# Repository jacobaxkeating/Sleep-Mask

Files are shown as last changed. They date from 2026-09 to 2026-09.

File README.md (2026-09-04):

# Circadian Sleep Mask

## Overview
A battery powered sleep mask that gradually illuminates the inside of the mask as the user's alarm approaches. The user sets their sleep duration by pressing a button on the housing, and the device begins lighting up that many hours later. Waking this way is closer to how the body wakes naturally, easing the user out of sleep rather than jolting them awake. It reduces sleep inertia, the grogginess and disorientation that follows an abrupt alarm

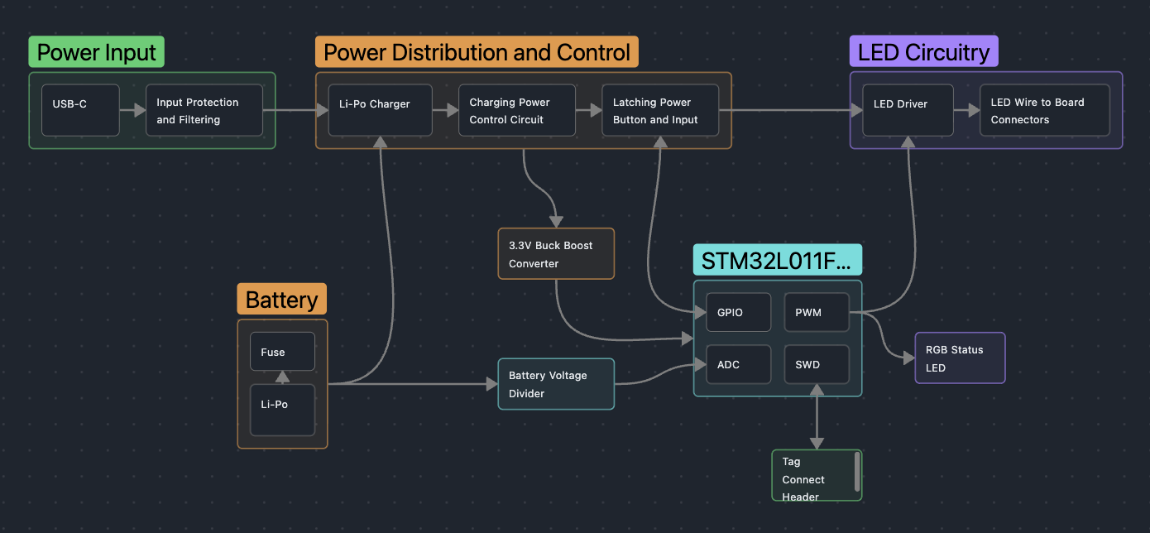
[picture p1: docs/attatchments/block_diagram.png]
Block Diagram


[Schematic (PDF)](outputs/schematic/sleep_mask.pdf)

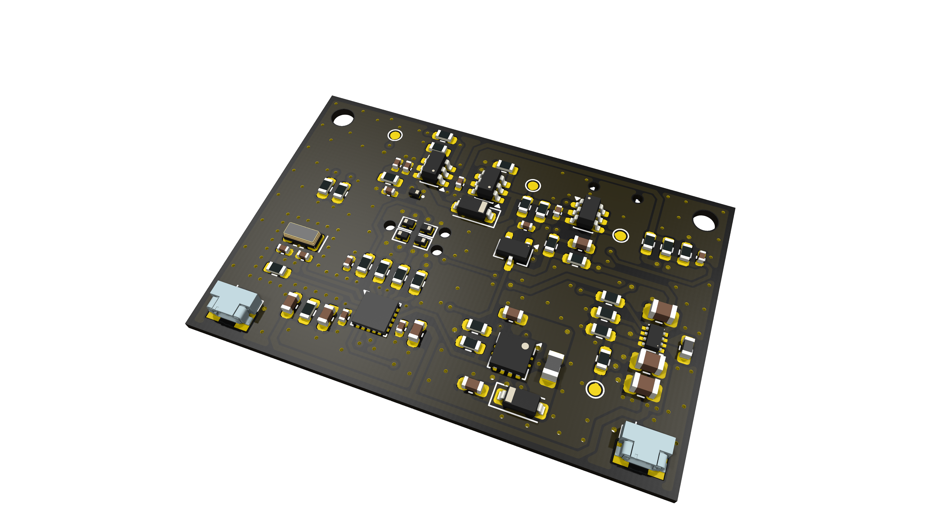
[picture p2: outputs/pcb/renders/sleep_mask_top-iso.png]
Sleep mask Front PCB

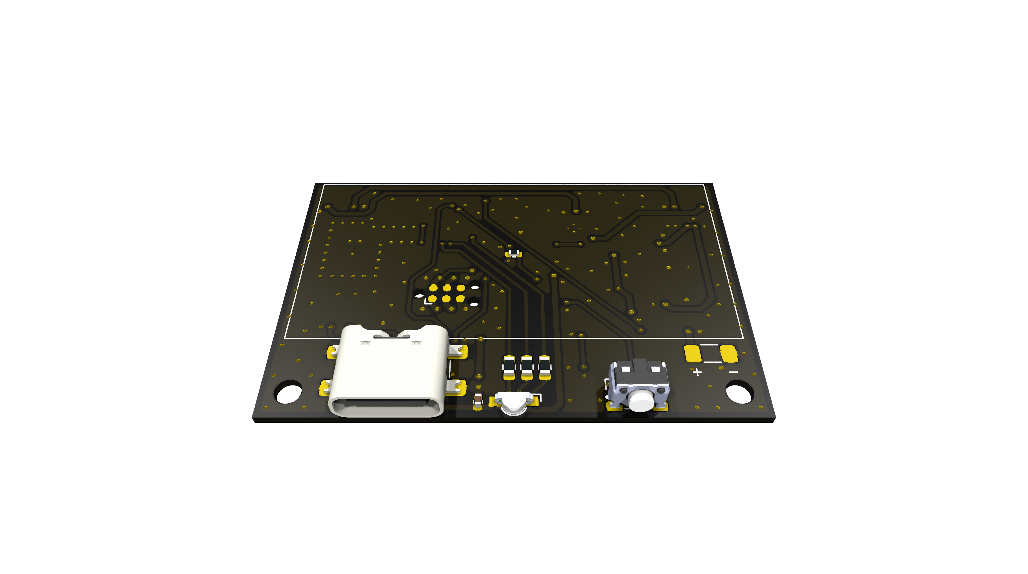
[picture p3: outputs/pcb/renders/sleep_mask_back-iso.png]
Sleep mask Back PCB


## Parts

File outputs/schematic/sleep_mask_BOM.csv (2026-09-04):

Reference | Value | Qty | MPN1 | Manufacturer1 | Footprint | Datasheet | COO | DNP | Description | MPN2 | Manufacturer2
BT1 | LP802036JU | 1 |  |  | Resistor_SMD:R_1206_3216Metric_Pad1.30x1.75mm_HandSolder | https://www.jauch.com/downloadfile/5ef1edcfd8b3ac6cf0afebf9dd427a79b/matd_248862_20220510_480mah_-_lp802036ju_1s1p_2_wire_50mm.pdf |  |  | BATTERY 3.7V 500MAH
C1,C2,C3,C4,C11,L2 | 1u | 6 |  |  | Capacitor_SMD:C_0402_1005Metric,Inductor_SMD:L_0603_1608Metric | https://mm.digikey.com/Volume0/opasdata/d220001/medias/docus/609/CL05A105KO5NNNC_Spec_5-2-19.pdf,https://search.murata.co.jp/Ceramy/image/img/P02/JETE243A-003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 |  |  | CAP CER 1UF 16V X5R 0402,FIXED IND 1UH 1.7A 128 MOHM SMD
C5,C7,C14,C15,C17,C18 | 100n | 6 |  |  | Capacitor_SMD:C_0402_1005Metric | https://mm.digikey.com/Volume0/opasdata/d220001/medias/docus/609/CL05B104KO5NNNC.pdf |  |  | CAP CER 0.1UF 16V X7R 0402
C6,C16,C19,C20 | 10u | 4 |  |  | Capacitor_SMD:C_0603_1608Metric | https://mm.digikey.com/Volume0/opasdata/d220001/medias/docus/43/CL10X106MO8NRNC_Spec.pdf |  |  | CAP CER 10UF 16V X6S 0603
C8,C9,C10 | 22u | 3 |  |  | Capacitor_SMD:C_0805_2012Metric | https://mm.digikey.com/Volume0/opasdata/d220001/medias/docus/339/CL21A226MAYNNNE_Spec.pdf |  |  | CAP CER 22UF 25V X5R 0805
C12,C13,L3 | 4.7u | 3 |  |  | Capacitor_SMD:C_0603_1608Metric,Inductor_SMD:L_0805_2012Metric | https://product.tdk.com/en/system/files |  |  | CAP CER 4.7UF 35V X5R 0603,FIXED IND 4.7UH 600MA 180 MOHM
C21,C22 | 8p | 2 |  |  | Capacitor_SMD:C_0402_1005Metric | https://mm.digikey.com/Volume0/opasdata/d220001/medias/docus/7513/DataSheet_CL05C080DB51PN_20251013.pdf |  |  | CAP CER 8PF 50V C0G/NP0 0402
D1,D5 | MBR0520LT1G | 2 |  |  | Diode_SMD:D_SOD-123 | https://www.onsemi.com/pdf/datasheet/mbr0520lt1-d.pdf |  |  | DIODE SCHOTTKY 20V 500MA SOD123
D2,D3 | TPD1E10B06DPYR | 2 |  |  | Package_SON:Texas_DPY0002A_0.6x1mm_P0.65mm | https://www.ti.com/general/docs/suppproductinfo.tsp?distId=10 |  |  | TVS DIODE 5.5VWM 14VC 2X1SON
D4 | BAV99,215 | 1 |  |  | Package_TO_SOT_SMD:TSOT-23 | https://assets.nexperia.com/documents/data-sheet/BAV99.pdf |  |  | DIODE ARR GP 100V 215MA TO-236AB
D6,D7,D8,D9 | DF2B5M4CT,L3F | 4 |  |  | Diode_SMD:D_SOD-882 | https://toshiba.semicon-storage.com/info/docget.jsp?did=55770&prodName=DF2B5M4CT |  |  | TVS DIODE 3.6VWM 15VC CST2
D10 | APFA3010 | 1 |  |  | LED_SMD:LED_Kingbright_APFA3010_3x1.5mm_Horizontal | https://www.KingbrightUSA.com/images/catalog/SPEC/APFA3010LSEEZGKQBKC.pdf |  |  | LED RGB CLEAR 4SMD R/A
F1 | FUSE | 1 |  |  | Resistor_SMD:R_0603_1608Metric | https://www.vishay.com/docs/28747/mfuserie.pdf |  |  | FUSE BOARD MOUNT 1A 32VDC 0603
H3 | 2147192020 | 1 |  |  |  | https://www.molex.com/en-us/products/part-detail/2147192020?display=pdf |  |  | CONN HDR HSG 2POS 0.80MM
H4 | 2147205001 | 1 |  |  |  | https://www.molex.com/pdm_docs/sd/2147205001_sd.pdf |  |  | ZERO-HACHI 0.8 CRIMP TERM #30-32
J1 | USB4135-GF-A | 1 |  |  | Connector_USB:USB_C_Receptacle_GCT_USB4135-GF-A_6P_TopMnt_Horizontal | https://gct.co/files/specs/usb4135-spec.pdf |  |  | USB C REC GF RA 6P SMT & SMT SHE
J2,J4 | 2147210021 | 2 |  |  | sleep_mask:2147210021 | https://www.molex.com/en-us/products/part-detail/2147210021?display=pdf |  |  | ZERO-HACHI 0.8 HDR SR RA ETP AU
L1 | 27n | 1 |  |  | Inductor_SMD:L_0603_1608Metric | https://search.murata.co.jp/Ceramy/image/img/P02/JELF243B-0002.pdf |  | DNP | FIXED IND 27NH 500MA 550 MOHM
Q1 | DMP2240UDM | 1 |  |  | Package_TO_SOT_SMD:SOT-23-6 | https://www.diodes.com/assets/Datasheets/ds31197.pdf |  |  | MOSFET 2P-CH 20V 2A SOT26
Q2 | DMC2700UDM-7 | 1 |  |  | Package_TO_SOT_SMD:SOT-23-6 | https://www.diodes.com/assets/Datasheets/DMC2700UDM.pdf |  |  | MOSFET N/P-CH 20V 1.34A SOT26
R1,R25,R27 | 0 | 3 |  |  | Resistor_SMD:R_0603_1608Metric | https://yageogroup.com/content/datasheet/asset/file/PYU-RC_GROUP_51_ROHS_L |  |  | RES 0 OHM JUMPER 1/10W 0603
R2,R6,R9,R13,R16,R20,R28 | 10k | 7 |  |  | Resistor_SMD:R_0603_1608Metric | https://www.koaspeer.com/pdfs/RK73H.pdf |  |  | RES 10K OHM 1% 1/10W 0603
R3,R4 | 5.1k | 2 |  |  | Resistor_SMD:R_0603_1608Metric | https://www.koaspeer.com/pdfs/RK73H.pdf |  |  | RES 5.1K OHM 1% 1/10W 0603
R5 | 5.6k | 1 |  |  | Resistor_SMD:R_0603_1608Metric | https://yageogroup.com/content/datasheet/asset/file/PYU-RC_GROUP_51_ROHS_L |  |  | RES 5.6K OHM 1% 1/10W 0603
R7,R8,R10 | 100k | 3 |  |  | Resistor_SMD:R_0603_1608Metric | https://www.koaspeer.com/pdfs/RK73H.pdf |  |  | RES 100K OHM 1% 1/10W 0603
R11,R14 | 300k | 2 |  |  | Resistor_SMD:R_0603_1608Metric | https://www.koaspeer.com/pdfs/RK73H.pdf |  |  | RES 300K OHM 1% 1/10W 0603
R12 | 511k | 1 |  |  | Resistor_SMD:R_0603_1608Metric | https://www.koaspeer.com/pdfs/RK73H.pdf |  |  | RES 511K OHM 1% 1/10W 0603
R15 | 91k | 1 |  |  | Resistor_SMD:R_0603_1608Metric | https://yageogroup.com/content/datasheet/asset/file/PYU-RC_GROUP_51_ROHS_L |  |  | RES 91K OHM 1% 1/10W 0603
R17,R18,R19 | 49R9 | 3 |  |  | Resistor_SMD:R_0603_1608Metric | https://yageogroup.com/content/datasheet/asset/file/PYU-RC_GROUP_51_ROHS_L |  |  | RES 49.9 OHM 1% 1/10W 0603
R21 | R | 1 |  |  | Resistor_SMD:R_0603_1608Metric |  |  |  | ~
R22,R23,R26 | 1k | 3 |  |  | Resistor_SMD:R_0603_1608Metric | https://www.koaspeer.com/pdfs/RK73H.pdf |  |  | RES 1K OHM 1% 1/8W 0603
R24 | 49R9 | 1 |  |  | Resistor_SMD:R_0603_1608Metric | https://yageogroup.com/content/datasheet/asset/file/PYU-RC_GROUP_51_ROHS_L |  | DNP | RES 49.9 OHM 1% 1/10W 0603
SW1 | PWR/IN | 1 |  |  | Button_Switch_SMD:SW_Push_1P1T-MP_NO_Horizontal_Alps_SKRTLAE010 | https://tech.alpsalpine.com/cms.media/product_spec_skrtlae010_en_1db35b7ed3.pdf |  |  | SWITCH TACTILE SPST-NO 0.05A 12V
TH1 | NTC | 1 |  |  | Resistor_SMD:R_0402_1005Metric | https://product.tdk.com/system/files/dam/doc/product/sensor/ntc/chip-ntc-thermistor/catalog/tpd_commercial_ntc-thermistor_ntcg_en.pdf |  |  | THERMISTOR NTC 10KOHM 3380K 0402
TP1 | VBUS | 1 |  |  | TestPoint:TestPoint_Pad_D1.0mm |  |  |  | ~
TP2 | BATT_VBUS | 1 |  |  | TestPoint:TestPoint_Pad_D1.0mm |  |  |  | ~
TP3 | VCC | 1 |  |  | TestPoint:TestPoint_Pad_D1.0mm |  |  |  | ~
TP4 | 3.3V | 1 |  |  | TestPoint:TestPoint_Pad_D1.0mm |  |  |  | ~
U1 | BQ21040DBV | 1 |  |  | Package_TO_SOT_SMD:SOT-23-6 | https://www.ti.com/general/docs/suppproductinfo.tsp?distId=10 |  |  | IC BATT CHG LI-ION 1CELL SOT23-6
U2 | TPS631000 | 1 |  |  | Package_TO_SOT_SMD:SOT-583-8 | https://www.ti.com/lit/ds/symlink/tps631000.pdf |  |  | IC REG BUCK BOOST ADJ 2A SOT-583
U3 | TPS61043 | 1 |  |  | Package_DFN_QFN:Texas_DRB0008A | https://www.ti.com/lit/ds/slvs465c/slvs465c.pdf |  |  | IC LED DRVR RGLTR PWM 60MA 8SON
U4 | STM32L011F3U6TR | 1 |  |  | Package_DFN_QFN:ST_UFQFPN-20_3x3mm_P0.5mm | https://www.st.com/resource/en/datasheet/stm32l011f3.pdf |  |  | IC MCU 32BIT 8KB FLASH 20UFQFPN
Y1 | 830009706 | 1 |  |  | Crystal:Crystal_SMD_G8-2Pin_3.2x1.5mm | https://www.we-online.com/components/products/datasheet/830009706.pdf |  |  | CRYSTAL 32.7680KHZ 9PF SMD

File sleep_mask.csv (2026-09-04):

Reference | Qty | Value | Description | Manufacturer_Part_Number | DNP | Exclude from BOM | Exclude from Board | MPN | Manufacturer
BT1 | 1 | LP802036JU | BATTERY 3.7V 500MAH | LP802036JU +PCM+2IC+2 WIRES 50MM |  |  |  |  | Jauch Quartz
C1,C2,C3,C4,C11 | 5 | 1u | CAP CER 1UF 16V X5R 0402 | CL05A105KO5NNNC |  |  |  |  | Samsung Electro-Mechanics
C5,C7,C14,C15,C17,C18 | 6 | 100n | CAP CER 0.1UF 16V X7R 0402 | CL05B104KO5NNNC |  |  |  |  | Samsung Electro-Mechanics
C6,C16,C19,C20 | 4 | 10u | CAP CER 10UF 16V X6S 0603 | CL10X106MO8NRNC |  |  |  |  | Samsung Electro-Mechanics
C8,C9,C10 | 3 | 22u | CAP CER 22UF 25V X5R 0805 | CL21A226MAYNNNE |  |  |  |  | Samsung Electro-Mechanics
C12,C13 | 2 | 4.7u | CAP CER 4.7UF 35V X5R 0603 | GRM188R6YA475KE15D |  |  |  |  | Murata Electronics
C21,C22 | 2 | 8p | CAP CER 8PF 50V C0G/NP0 0402 | CL05C080DB51PNC |  |  |  |  | Samsung Electro-Mechanics
D1,D5 | 2 | MBR0520LT1G | DIODE SCHOTTKY 20V 500MA SOD123 | MBR0520LT1G |  |  |  |  | onsemi
D2,D3 | 2 | TPD1E10B06DPYR | TVS DIODE 5.5VWM 14VC 2X1SON | TPD1E10B06DPYR |  |  |  |  | Texas Instruments
D4 | 1 | BAV99,215 | DIODE ARR GP 100V 215MA TO-236AB | BAV99,215 |  |  |  |  | Nexperia USA Inc.
D6,D7,D8,D9 | 4 | DF2B5M4CT,L3F | TVS DIODE 3.6VWM 15VC CST2 | DF2B5M4CT,L3F |  |  |  |  | Toshiba Semiconductor and Storage
D10 | 1 | APFA3010 | LED RGB CLEAR 4SMD R/A | APFA3010LSEEZGKQBKC |  |  |  |  | Kingbright
F1 | 1 | FUSE | FUSE BOARD MOUNT 1A 32VDC 0603 | MFU0603FF01000P500 |  |  |  |  | Vishay
H1,H2 | 2 | MountingScrew | Mounting screw |  |  | Excluded from BOM
H3 | 1 | 2147192020 | CONN HDR HSG 2POS 0.80MM | 2147192020 |  |  | Excluded from board |  | Molex
H4 | 1 | 2147205001 | ZERO-HACHI 0.8 CRIMP TERM #30-32 | 2147205001 |  |  | Excluded from board |  | Molex
H5,H6 | 2 | M2 | Mounting Hole without connection |  |  | Excluded from BOM
J1 | 1 | USB4135-GF-A | USB C REC GF RA 6P SMT & SMT SHE | USB4135-GF-A |  |  |  |  | GCT
J2,J4 | 2 | 2147210021 | ZERO-HACHI 0.8 HDR SR RA ETP AU | 2147210021 |  |  |  |  | Molex
J3 | 1 | SWD | ~ | ~ |  | Excluded from BOM
L1 | 1 | 27n | FIXED IND 27NH 500MA 550 MOHM | LQG18HN27NJ00D | DNP |  | Excluded from board |  | Murata Electronics
L2 | 1 | 1u | FIXED IND 1UH 1.7A 128 MOHM SMD | DFE18SAN1R0MG0L |  |  |  |  | Murata Electronics
L3 | 1 | 4.7u | FIXED IND 4.7UH 600MA 180 MOHM | MLZ2012N4R7LT000 |  |  |  |  | TDK
Q1 | 1 | DMP2240UDM | MOSFET 2P-CH 20V 2A SOT26 | DMP2240UDM |  |  |  |  | Diodes Incorporated
Q2 | 1 | DMC2700UDM-7 | MOSFET N/P-CH 20V 1.34A SOT26 | DMC2700UDM-7 |  |  |  |  | Diodes Incorporated
R1,R24,R26 | 3 | 0 | RES 0 OHM JUMPER 1/10W 0603 | RC0603JR-070RL |  |  |  |  | YAGEO
R2,R6,R9,R13,R16,R27 | 6 | 10k | RES 10K OHM 1% 1/10W 0603 | RK73H1JTTD1002F |  |  |  |  | KOA Speer Electronics, Inc.
R3,R4 | 2 | 5.1k | RES 5.1K OHM 1% 1/10W 0603 | RK73H1JTTD5101F |  |  |  |  | KOA Speer Electronics, Inc.
R5 | 1 | 5.6k | RES 5.6K OHM 1% 1/10W 0603 | RC0603FR-075K6L |  |  |  |  | YAGEO
R7,R8,R10 | 3 | 100k | RES 100K OHM 1% 1/10W 0603 | RK73H1JTTD1003F |  |  |  |  | KOA Speer Electronics, Inc.
R11,R14 | 2 | 300k | RES 300K OHM 1% 1/10W 0603 | RK73H1JTTD3003F |  |  |  |  | KOA Speer Electronics, Inc.
R12 | 1 | 511k | RES 511K OHM 1% 1/10W 0603 | RK73H1JTTD5113F |  |  |  |  | KOA Speer Electronics, Inc.
R15 | 1 | 91k | RES 91K OHM 1% 1/10W 0603 | RC0603FR-0791KL |  |  |  |  | YAGEO
R17,R18,R19 | 3 | 49R9 | RES 49.9 OHM 1% 1/10W 0603 | RC0603FR-0749R9L |  |  |  |  | YAGEO
R20 | 1 | R | ~ | ~
R21,R22,R25 | 3 | 1k | RES 1K OHM 1% 1/8W 0603 | RK73H1JTTD1001F |  |  |  |  | KOA Speer Electronics, Inc.
R23 | 1 | 49R9 | RES 49.9 OHM 1% 1/10W 0603 | RC0603FR-0749R9L | DNP |  | Excluded from board |  | YAGEO
SW1 | 1 | PWR/IN | SWITCH TACTILE SPST-NO 0.05A 12V | SKRTLAE010 |  |  |  |  | Alps Alpine
TH1 | 1 | NTC | THERMISTOR NTC 10KOHM 3380K 0402 | NTCG103JF103FT1 |  |  |  |  | TDK
TP1 | 1 | VBUS | ~ | ~
TP2 | 1 | BATT_VBUS | ~ | ~
TP3 | 1 | VCC | ~ | ~
TP4 | 1 | 3.3V | ~ | ~
U1 | 1 | BQ21040DBV | IC BATT CHG LI-ION 1CELL SOT23-6 | BQ21040DBVT |  |  |  |  | Texas Instruments
U2 | 1 | TPS631000 | IC REG BUCK BOOST ADJ 2A SOT-583 | TPS631000DRLR |  |  |  |  | Texas Instruments
U3 | 1 | TPS61043 | IC LED DRVR RGLTR PWM 60MA 8SON | TPS61043DRBR |  |  |  |  | Texas Instruments
U4 | 1 | STM32L011F3U6TR | IC MCU 32BIT 8KB FLASH 20UFQFPN | STM32L011F3U6TR |  |  |  |  | STMicroelectronics
Y1 | 1 | 830009706 | CRYSTAL 32.7680KHZ 9PF SMD | 830009706 |  |  |  | ABS05-32.768KHZ-9-T | Würth Elektronik

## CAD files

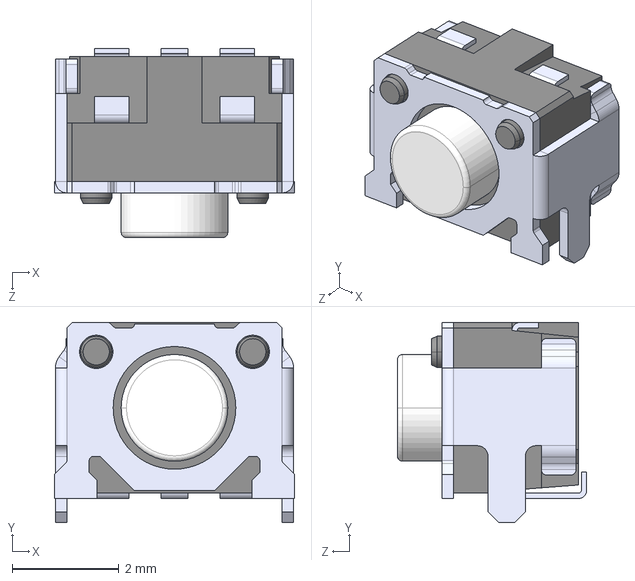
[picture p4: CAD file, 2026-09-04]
3dmodels/SKRTLAE010--3DModel-STEP-56544.STEP
4.50 x 3.75 x 3.55 mm

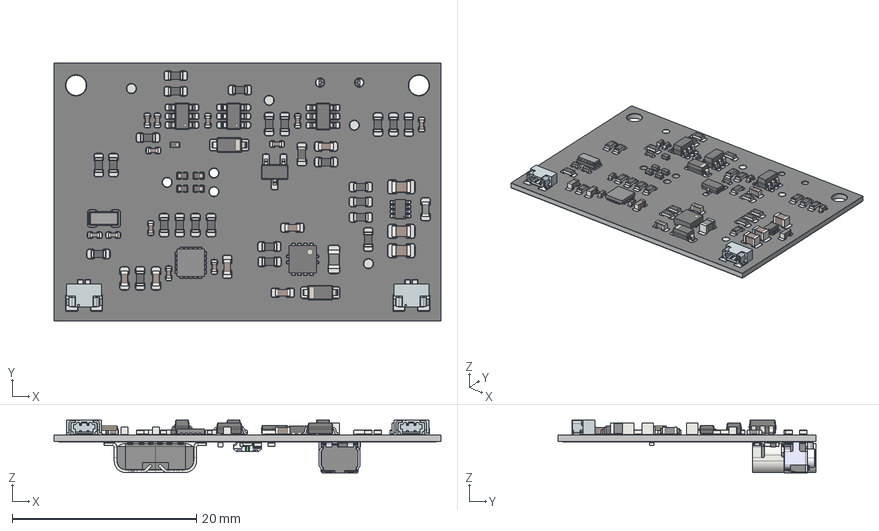
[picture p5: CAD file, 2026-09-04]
outputs/pcb/sleep_mask_3dmodel.step
42.0 x 28.0 x 5.73 mm
R_0603_1608Metric x 28
L_0805_2012Metric
SOT-23-6 x 3
C_0603_1608Metric x 6
C_0402_1005Metric x 13
D_SOD-882 x 6
C_0805_2012Metric x 3
TSOT-23
STM32L011F3U6TR
Texas_S-PVSON-N8
D_SOD-123 x 2
L_0603_1608Metric
SOT-583-8
Crystal_SMD_3215-2Pin_3.2x1.5mm
SKRTLAE010--3DModel-STEP-56544
USB_C_Receptacle_GCT_USB4135-GF-A_6P_TopMnt_Horizontal
APFA3010LSEEZGKQBKC
R_0402_1005Metric
sleep_mask_copper
sleep_mask_pad
sleep_mask_via
sleep_mask_soldermask x 2
sleep_mask_PCB

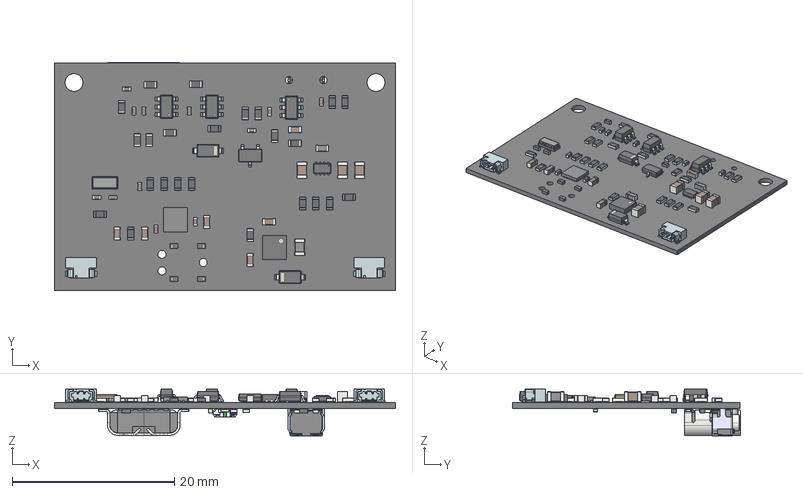
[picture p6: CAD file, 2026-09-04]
sleep_mask.step
42.0 x 28.0 x 5.73 mm
R_0603_1608Metric x 27
L_0805_2012Metric
SOT-23-6 x 3
C_0603_1608Metric x 6
C_0402_1005Metric x 13
D_SOD-882 x 6
C_0805_2012Metric x 3
TSOT-23
STM32L011F3U6TR
Texas_S-PVSON-N8
D_SOD-123 x 2
L_0603_1608Metric
SOT-583-8
Crystal_SMD_3215-2Pin_3.2x1.5mm
SKRTLAE010--3DModel-STEP-56544
USB_C_Receptacle_GCT_USB4135-GF-A_6P_TopMnt_Horizontal
APFA3010LSEEZGKQBKC
R_0402_1005Metric
sleep_mask_PCB

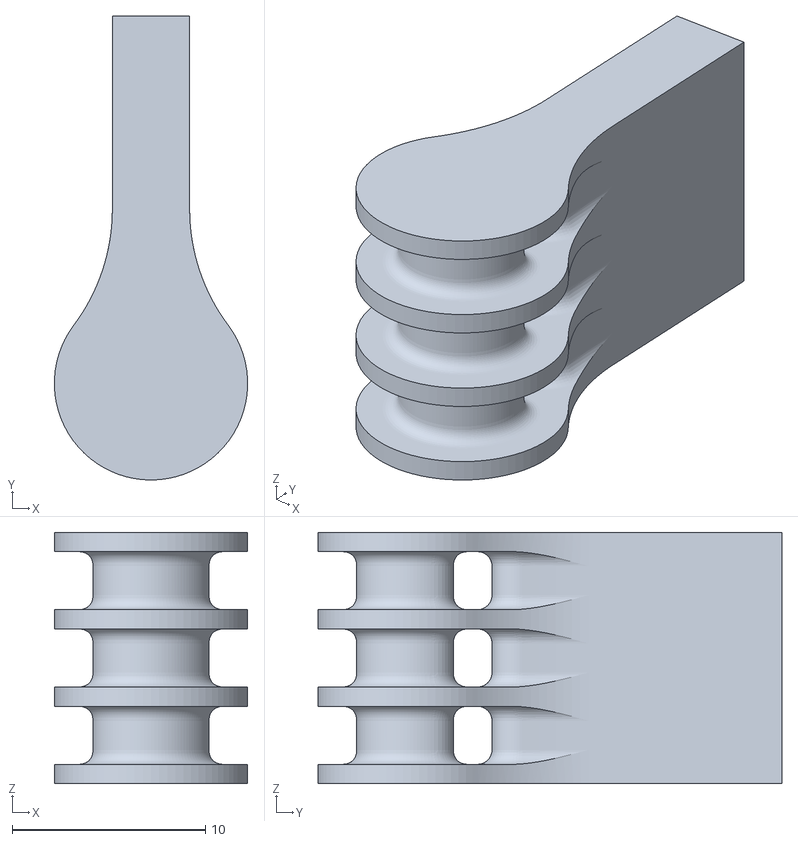
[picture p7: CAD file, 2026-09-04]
Body1.stl
9.99 x 24.0 x 13.0

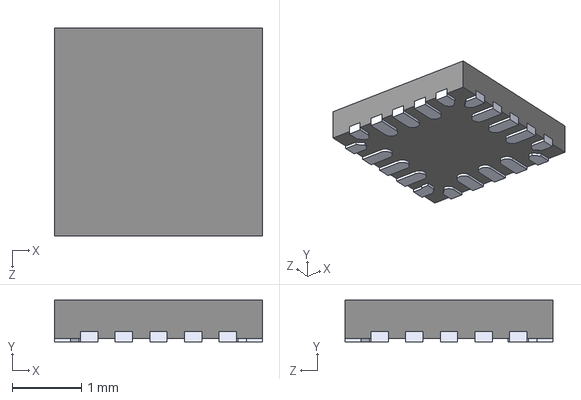
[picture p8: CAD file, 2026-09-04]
3dmodels/STM32L011F3U6TR.step
3.00 x 0.6 x 3.00 mm

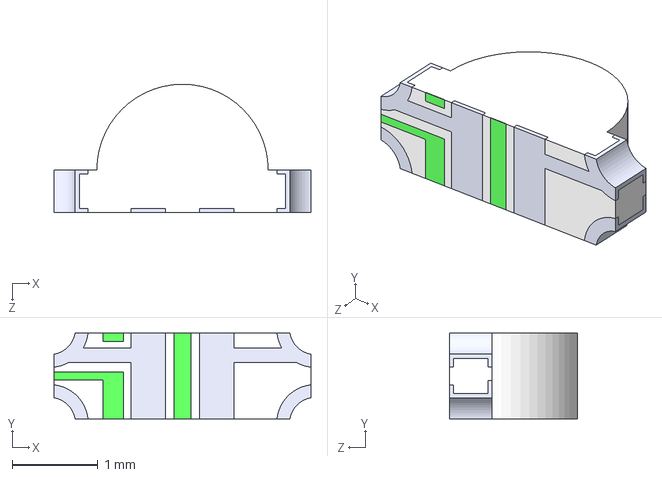
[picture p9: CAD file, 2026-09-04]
3dmodels/APFA3010LSEEZGKQBKC.STEP
3.00 x 1.00 x 1.50 mm

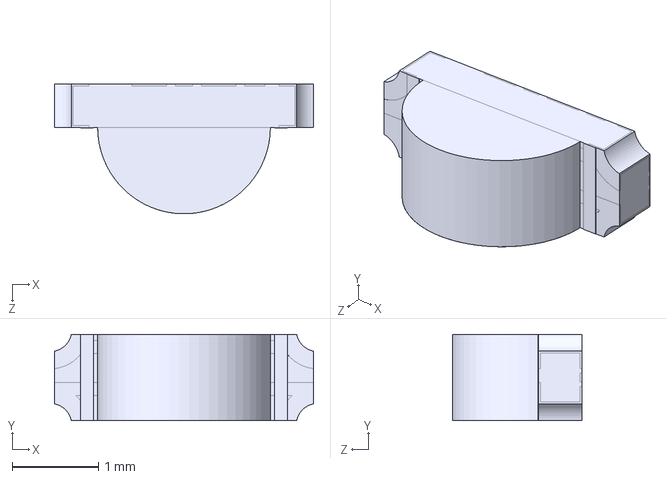
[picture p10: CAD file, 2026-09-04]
3dmodels/APFA3010.IGS
3.00 x 1.00 x 1.50 mm

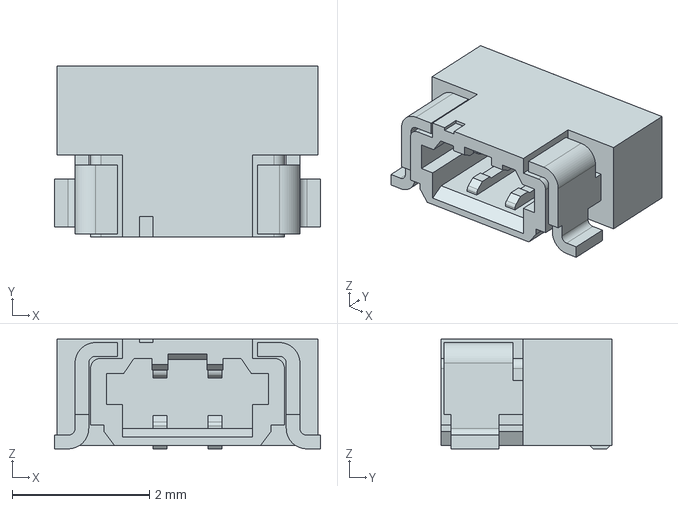
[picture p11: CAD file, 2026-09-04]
3dmodels/2147210021.stp
3.88 x 2.50 x 1.60 mm

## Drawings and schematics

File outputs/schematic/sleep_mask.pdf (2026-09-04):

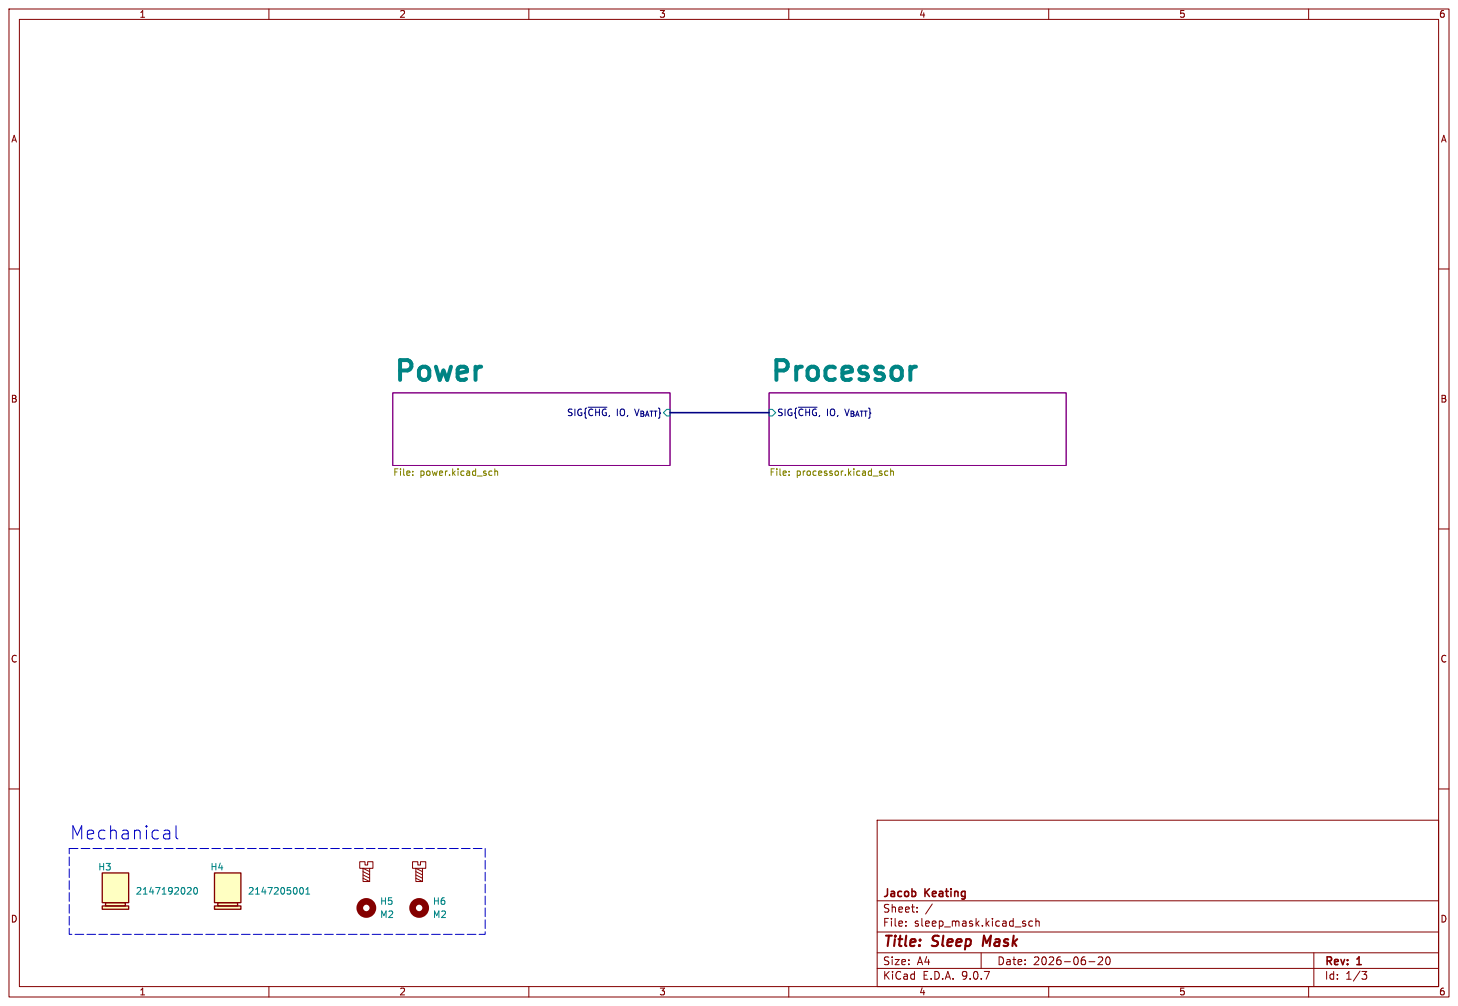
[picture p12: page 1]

SIG{~{CHG},IO, V_{BATT}}

Id: 1/3 Title: Sleep Mask

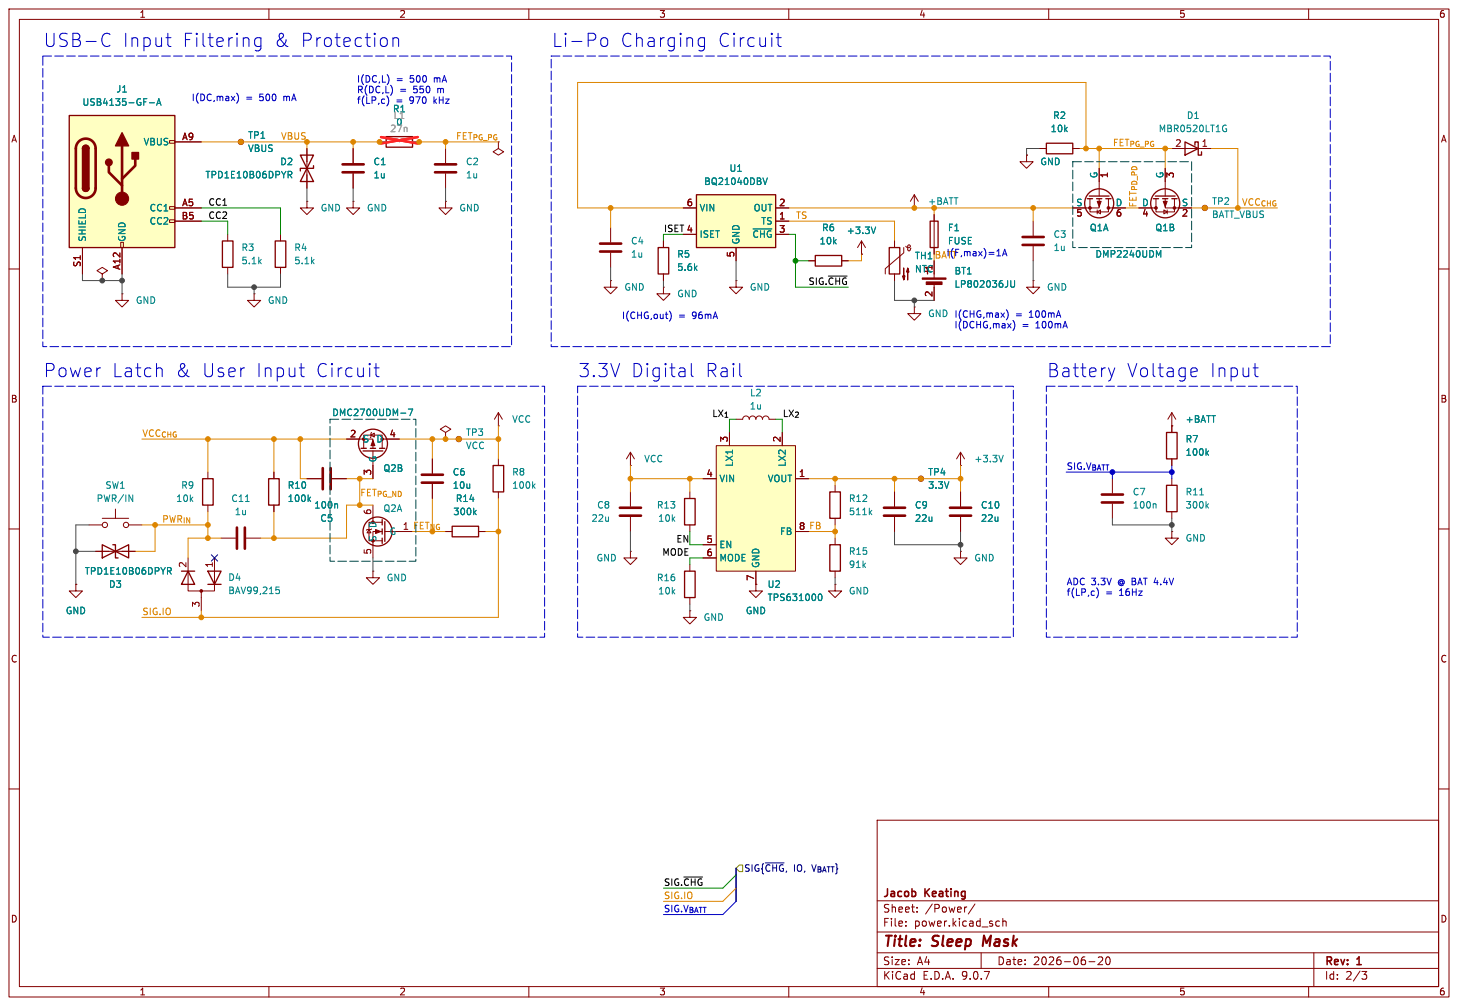
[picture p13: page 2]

5 OUT 2 TS 1 ~{CHG}3 U1 BQ21040DBV GND

5 OUT 2 TS 1 ~{CHG}3 GND

2 VOUT 1 FB 8 U2 TPS631000 GND GND

3 GND
91k SIG{~{CHG},IO, V_{BATT}}

Id: 2/3 Title: Sleep Mask

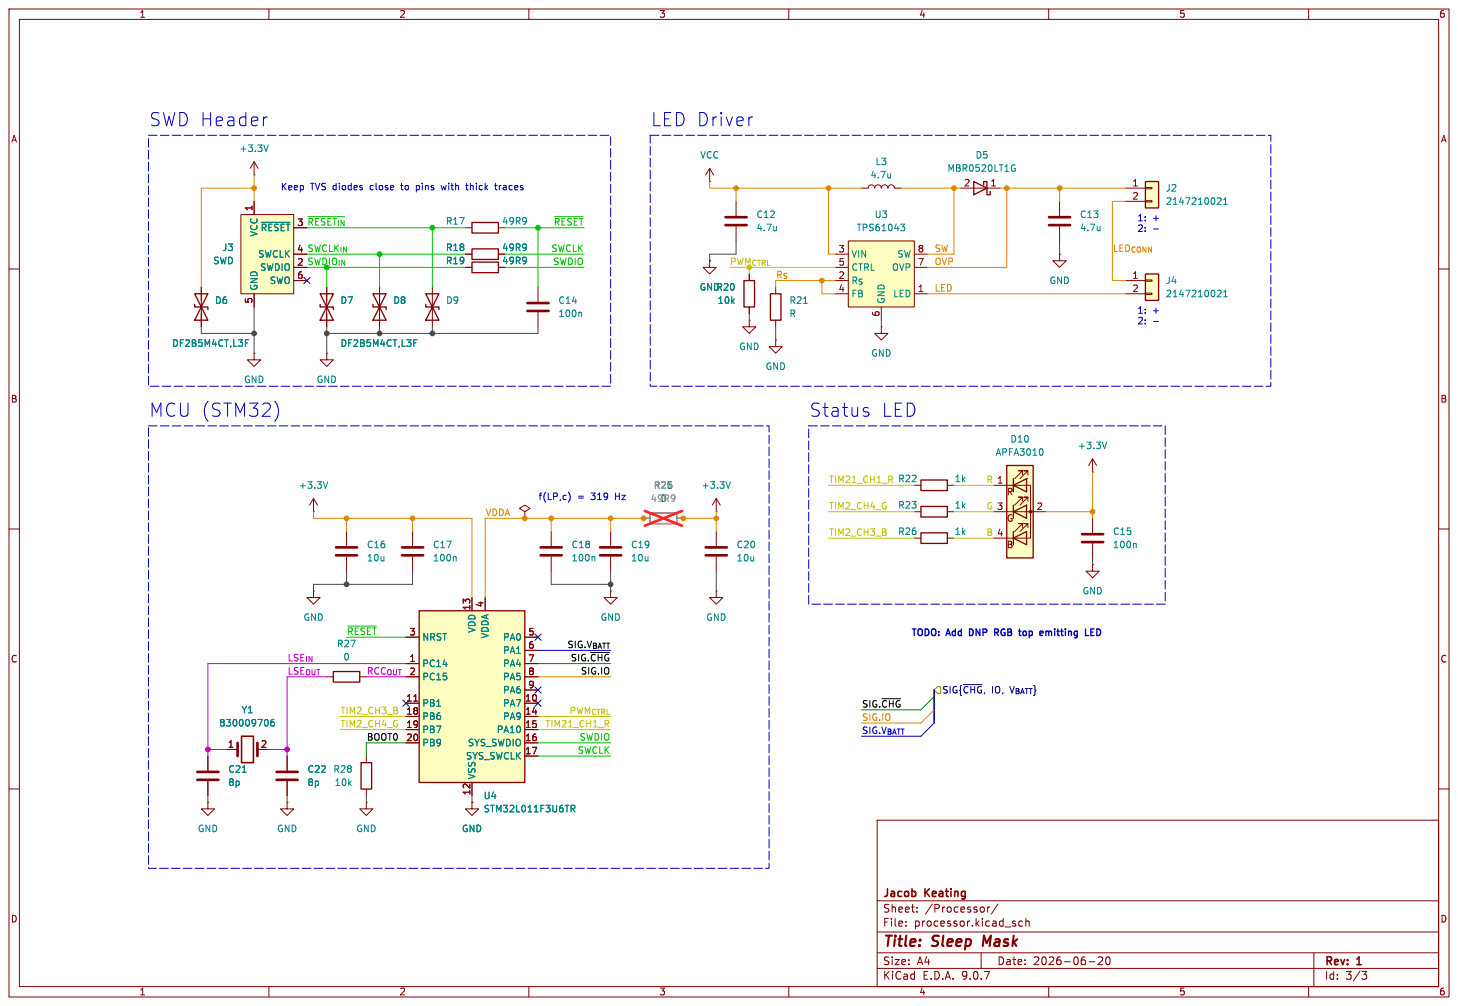
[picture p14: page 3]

5 ~{RESET}3 SWCLK 4 SWDIO 2 SWO 6

5 ~{RESET}3 SWCLK 4 SWDIO 2 SWO 6 R18 49R9 R19 49R9 GND

SIG{~{CHG},IO, V_{BATT}}

SIG.V_{BATT} SIG.IO

Id: 3/3 Title: Sleep Mask

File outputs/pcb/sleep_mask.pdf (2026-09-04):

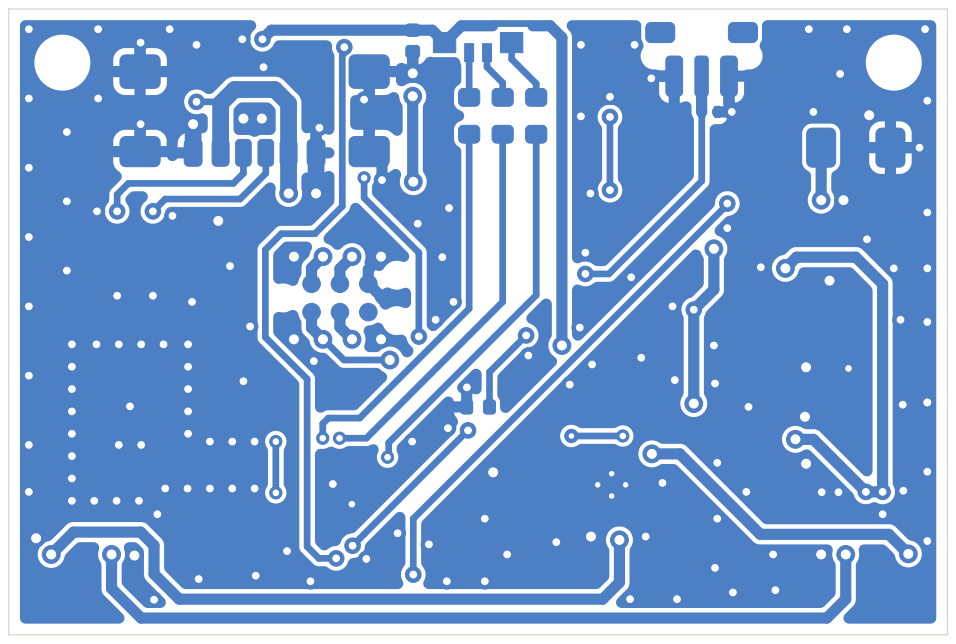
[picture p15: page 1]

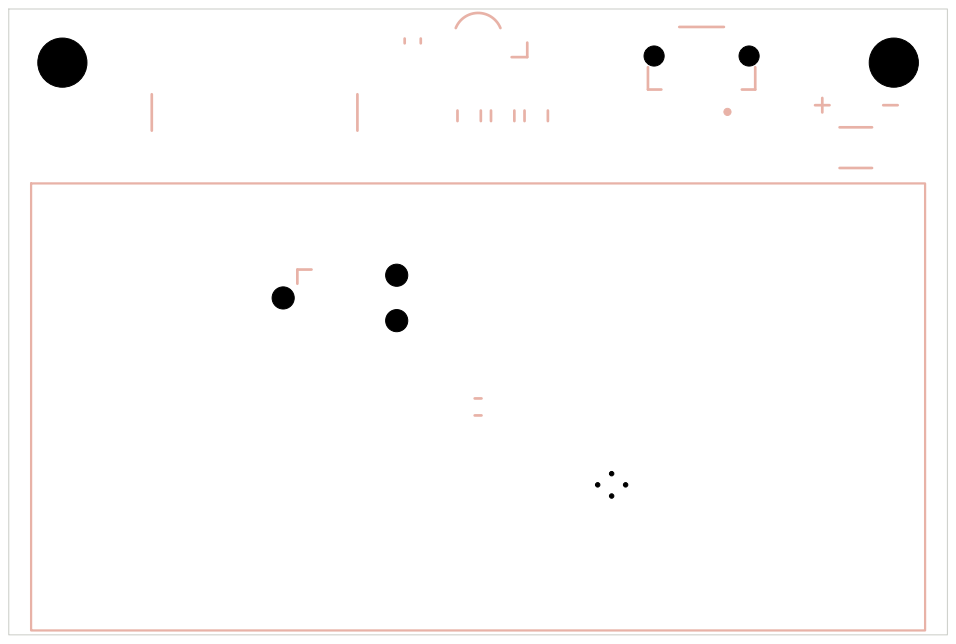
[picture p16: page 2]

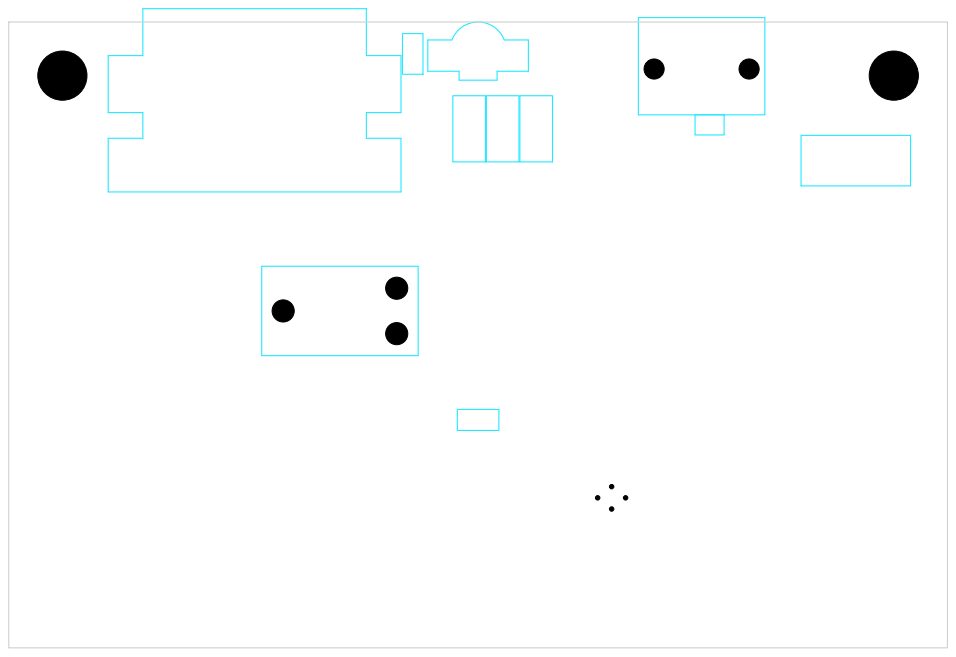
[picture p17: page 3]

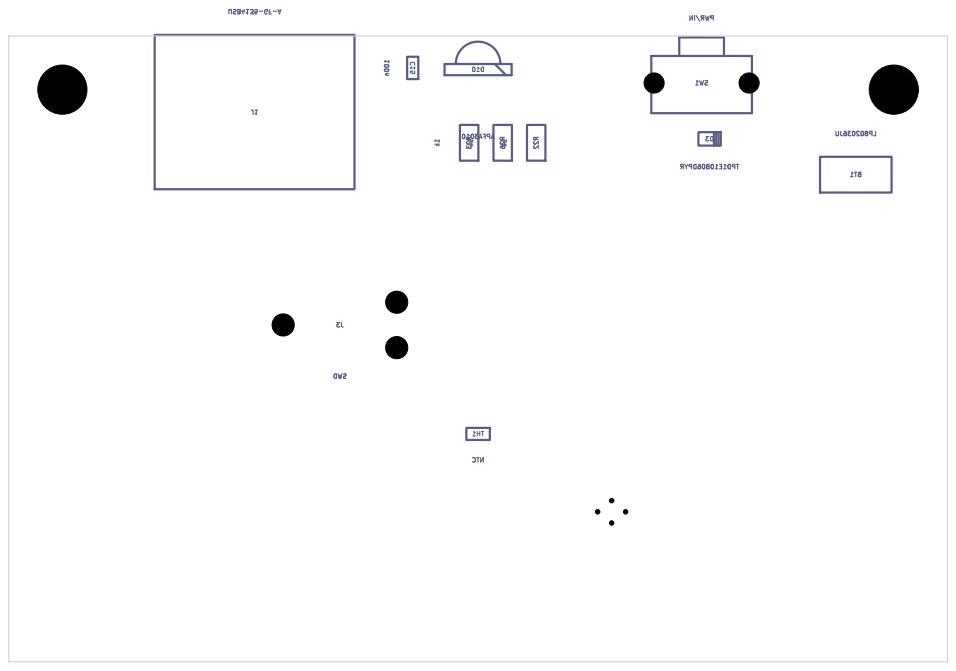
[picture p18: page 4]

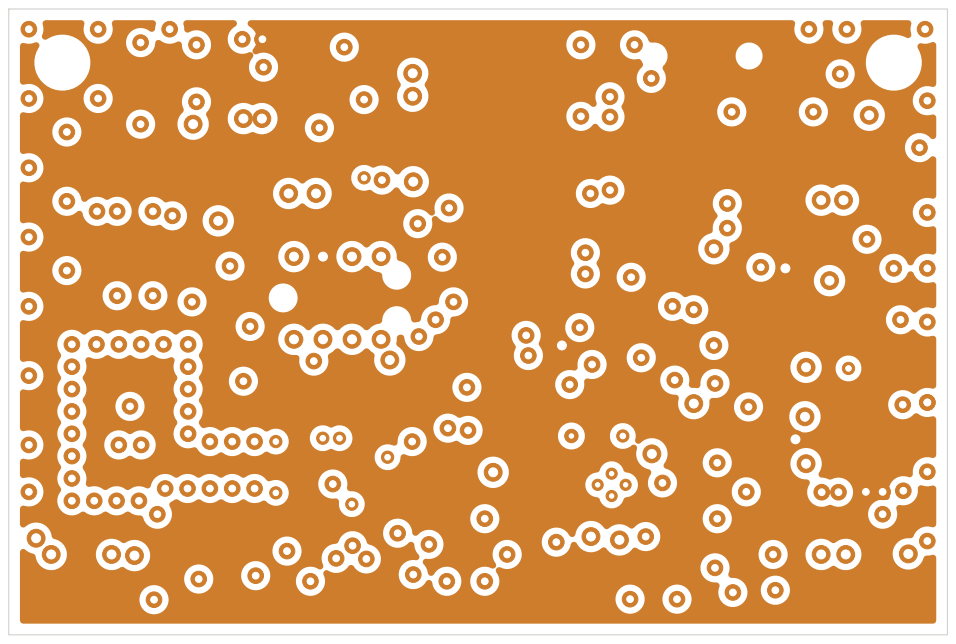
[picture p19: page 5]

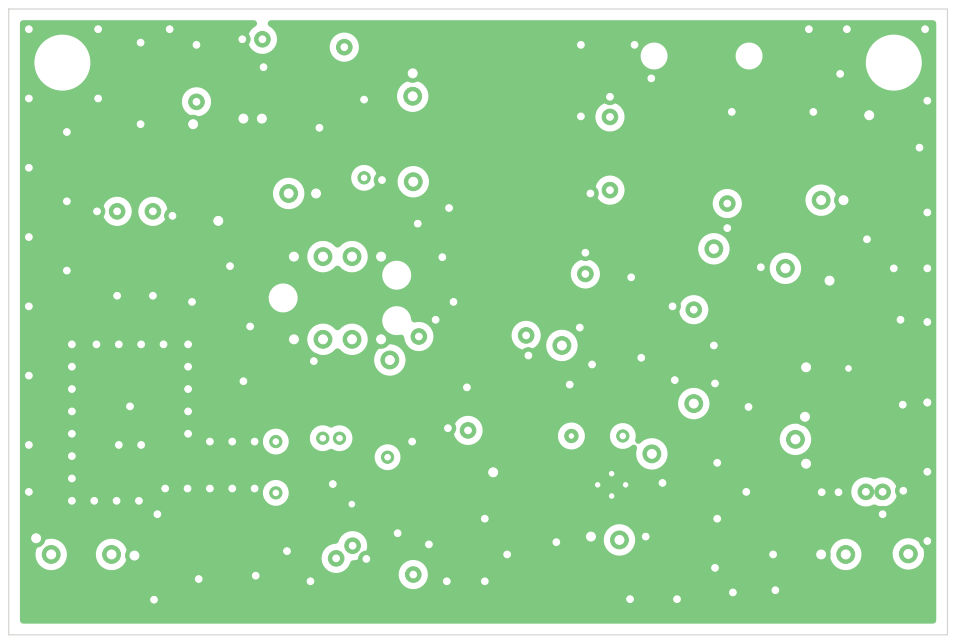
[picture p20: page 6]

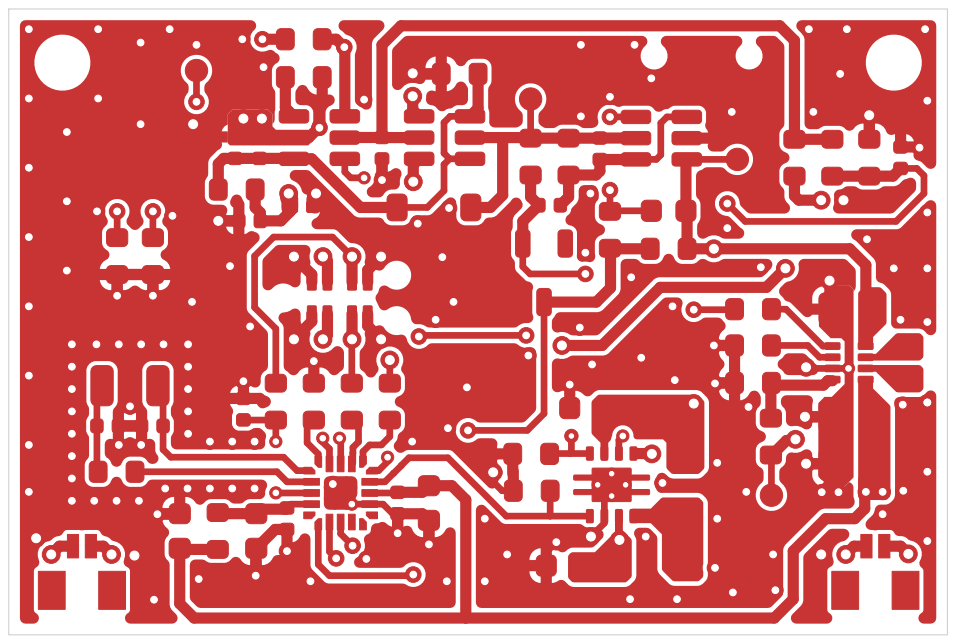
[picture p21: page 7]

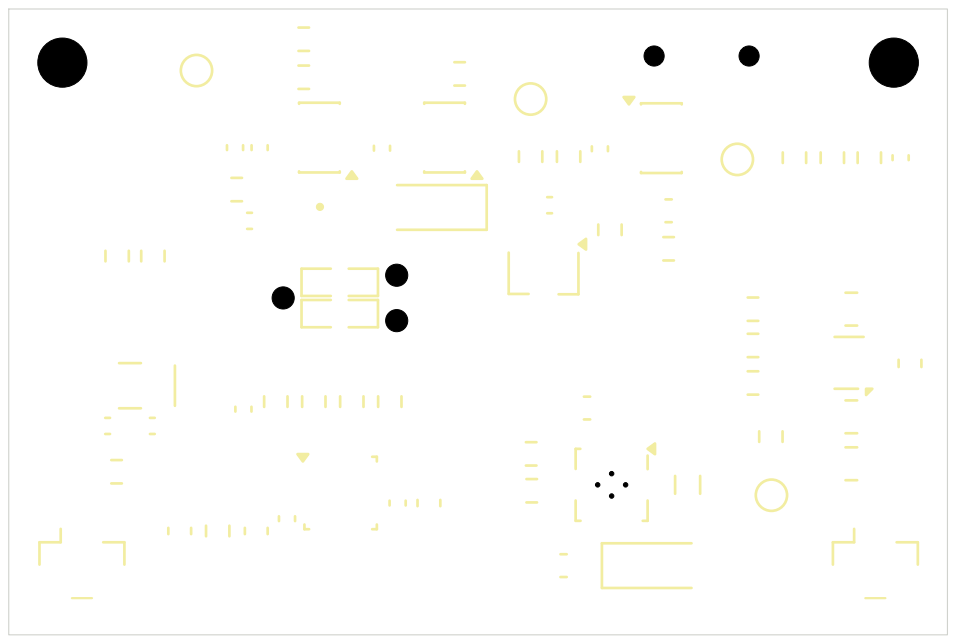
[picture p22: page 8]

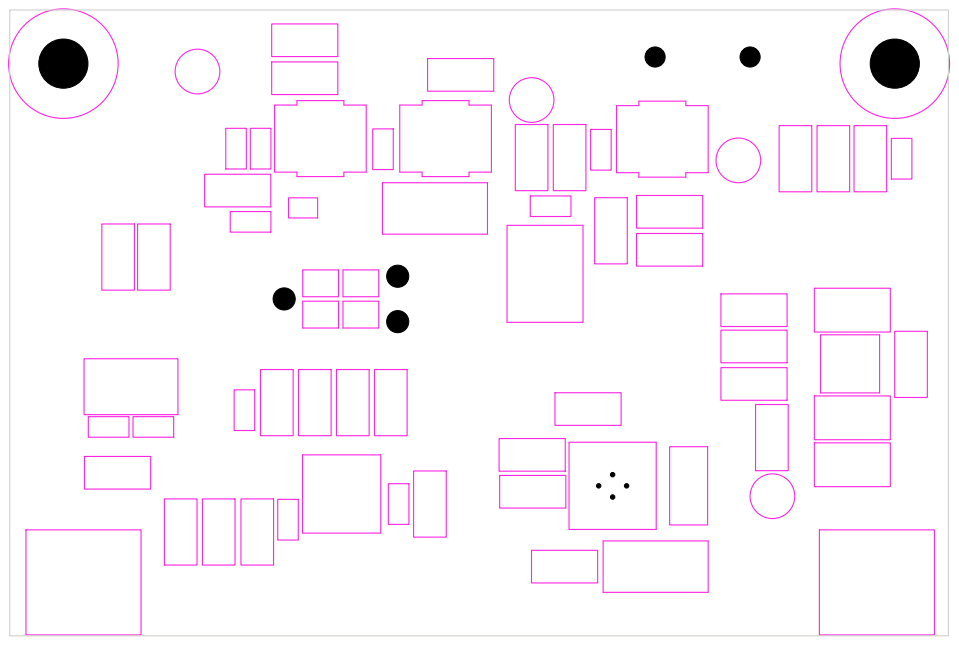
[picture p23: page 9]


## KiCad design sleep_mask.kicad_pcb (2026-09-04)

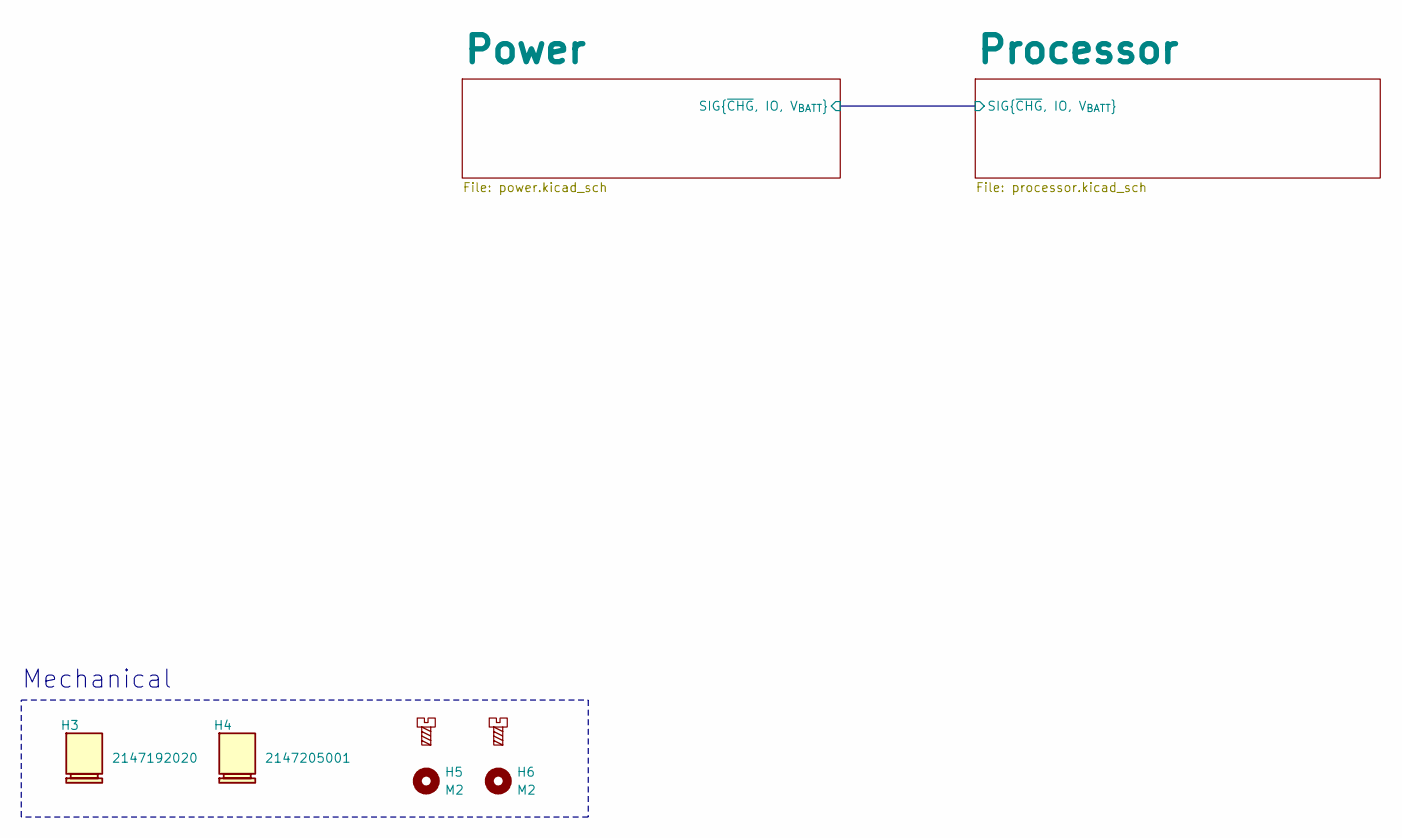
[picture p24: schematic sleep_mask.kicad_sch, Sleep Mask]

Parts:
H1, H2: MountingScrew
H3: 2147192020; Manufacturer_Part_Number 2147192020
H4: 2147205001; Manufacturer_Part_Number 2147205001
H5, H6: M2; MountingHole_2.2mm_M2

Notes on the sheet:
Mechanical

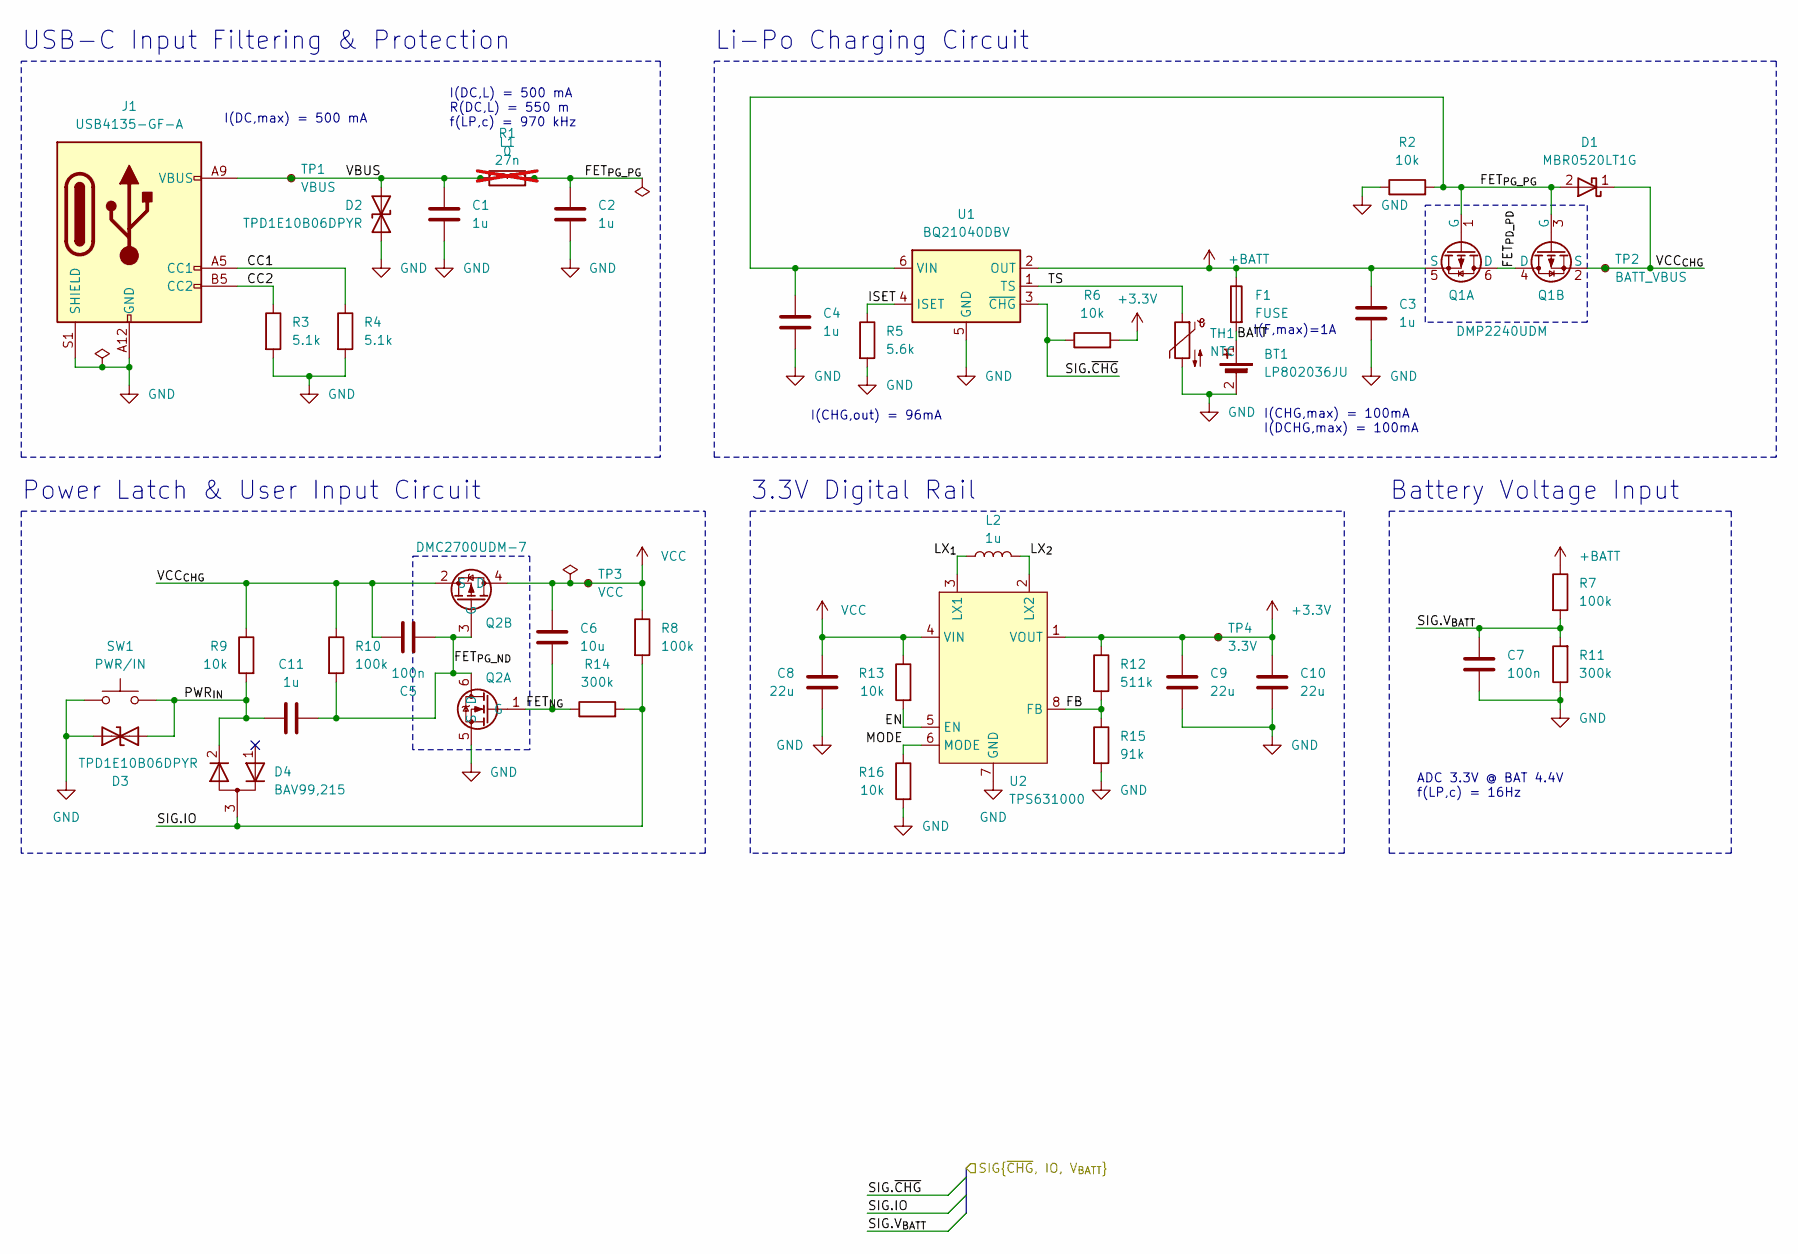
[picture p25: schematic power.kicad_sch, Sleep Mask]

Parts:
BT1: LP802036JU; R_1206_3216Metric_Pad1.30x1.75mm_HandSolder; Manufacturer_Part_Number LP802036JU +PCM+2IC+2 WIRES 50MM
C1, C2, C3, C4, C11: 1u; C_0402_1005Metric; Manufacturer_Part_Number CL05A105KO5NNNC
C5, C7: 100n; C_0402_1005Metric; Manufacturer_Part_Number CL05B104KO5NNNC
C6: 10u; C_0603_1608Metric; Manufacturer_Part_Number CL10X106MO8NRNC
C8, C9, C10: 22u; C_0805_2012Metric; Manufacturer_Part_Number CL21A226MAYNNNE
D1: MBR0520LT1G; D_SOD-123; Manufacturer_Part_Number MBR0520LT1G
D2, D3: TPD1E10B06DPYR; Texas_DPY0002A_0.6x1mm_P0.65mm; Manufacturer_Part_Number TPD1E10B06DPYR
D4: BAV99,215; TSOT-23; Manufacturer_Part_Number BAV99,215
F1: FUSE; R_0603_1608Metric; Manufacturer_Part_Number MFU0603FF01000P500
J1: USB4135-GF-A; USB_C_Receptacle_GCT_USB4135-GF-A_6P_TopMnt_Horizontal; Manufacturer_Part_Number USB4135-GF-A
L1: 27n; L_0603_1608Metric; Manufacturer_Part_Number LQG18HN27NJ00D; not fitted
L2: 1u; L_0603_1608Metric; Manufacturer_Part_Number DFE18SAN1R0MG0L
Q1: DMP2240UDM; SOT-23-6; Manufacturer_Part_Number DMP2240UDM
Q2: DMC2700UDM-7; SOT-23-6; Manufacturer_Part_Number DMC2700UDM-7
R1: 0; R_0603_1608Metric; Manufacturer_Part_Number RC0603JR-070RL
R2, R6, R9, R13, R16: 10k; R_0603_1608Metric; Manufacturer_Part_Number RK73H1JTTD1002F
R3, R4: 5.1k; R_0603_1608Metric; Manufacturer_Part_Number RK73H1JTTD5101F
R5: 5.6k; R_0603_1608Metric; Manufacturer_Part_Number RC0603FR-075K6L
R7, R8, R10: 100k; R_0603_1608Metric; Manufacturer_Part_Number RK73H1JTTD1003F
R11, R14: 300k; R_0603_1608Metric; Manufacturer_Part_Number RK73H1JTTD3003F
R12: 511k; R_0603_1608Metric; Manufacturer_Part_Number RK73H1JTTD5113F
R15: 91k; R_0603_1608Metric; Manufacturer_Part_Number RC0603FR-0791KL
SW1: PWR/IN; SW_Push_1P1T-MP_NO_Horizontal_Alps_SKRTLAE010; Manufacturer_Part_Number SKRTLAE010
TH1: NTC; R_0402_1005Metric; Manufacturer_Part_Number NTCG103JF103FT1
TP1: VBUS; TestPoint_Pad_D1.0mm
TP2: BATT_VBUS; TestPoint_Pad_D1.0mm
TP3: VCC; TestPoint_Pad_D1.0mm
TP4: 3.3V; TestPoint_Pad_D1.0mm
U1: BQ21040DBV; SOT-23-6; Manufacturer_Part_Number BQ21040DBVT
U2: TPS631000; SOT-583-8; Manufacturer_Part_Number TPS631000DRLR

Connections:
+3.3V: C9.2, C10.2, R6.2, R12.1, TP4.1, U2.1 (VOUT); also elsewhere on the board
+BATT: C3.1, F1.1, Q1.5 (S), R7.1, U1.2 (OUT)
/Power/BATT: BT1.1 (+), F1.2
/Power/CC1: J1.A5 (CC1), R4.1
/Power/CC2: J1.B5 (CC2), R3.1
/Power/EN: R13.2, U2.5 (EN)
/Power/FB: R12.2, R15.1, U2.8 (FB)
/Power/FET_{NG}: C6.2, Q2.1 (G), R14.1
/Power/FET_{PD_PD}: Q1.4 (D), Q1.6 (D)
/Power/FET_{PG_ND}: C5.2, C11.2, Q2.3 (G), Q2.6 (D), R10.2
/Power/FET_{PG_PG}: C2.1, C4.1, D1.2 (A), L1.2, Q1.1 (G), Q1.3 (G), R1.2, R2.2, U1.6 (VIN)
/Power/ISET: R5.1, U1.4 (ISET)
/Power/LX_{1}: L2.1, U2.3 (LX1)
/Power/LX_{2}: L2.2, U2.2 (LX2)
/Power/MODE: R16.1, U2.6 (MODE)
/Power/PWR_{IN}: C11.1, D3.2 (A2), D4.2 (K), R9.2, SW1.2
/Power/SIG.IO: D4.3 (common), R8.2, R14.2; also elsewhere on the board
/Power/SIG.V_{BATT}: C7.1, R7.2, R11.2; also elsewhere on the board
/Power/SIG.~CHG: R6.1, U1.3 (~CHG); also elsewhere on the board
/Power/TS: TH1.1, U1.1 (TS)
/Power/VBUS: C1.1, D2.2 (A2), J1.A9 (VBUS), J1.B9 (VBUS), L1.1, R1.1, TP1.1
/Power/VCC_{CHG}: C5.1, D1.1 (K), Q1.2 (S), Q2.2 (S), R9.1, R10.1, TP2.1
GND: BT1.2 (-), C1.2, C2.2, C3.2, C4.2, C7.2, C8.1, C9.1, C10.1, D2.1 (A1), D3.1 (A1), J1.A12 (GND), J1.B12 (GND), J1.S1 (SHIELD), Q2.5 (S), R2.1, R3.2, R4.2, R5.2, R11.1, R15.2, R16.2, SW1.1, TH1.2, U1.5 (GND), U2.7 (GND); also elsewhere on the board
VCC: C6.1, C8.2, Q2.4 (D), R8.1, R13.1, TP3.1, U2.4 (VIN); also elsewhere on the board

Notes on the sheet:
I(F,max)=1A
I(CHG,out) = 96mA
I(DC,max) = 500 mA
I(DC,L) = 500 mA R(DC,L) = 550 m f(LP,c) = 970 kHz
I(CHG,max) = 100mA I(DCHG,max) = 100mA
3.3V Digital Rail
Li-Po Charging Circuit
USB-C Input Filtering & Protection
Battery Voltage Input
Power Latch & User Input Circuit
ADC 3.3V @ BAT 4.4V f(LP,c) = 16Hz

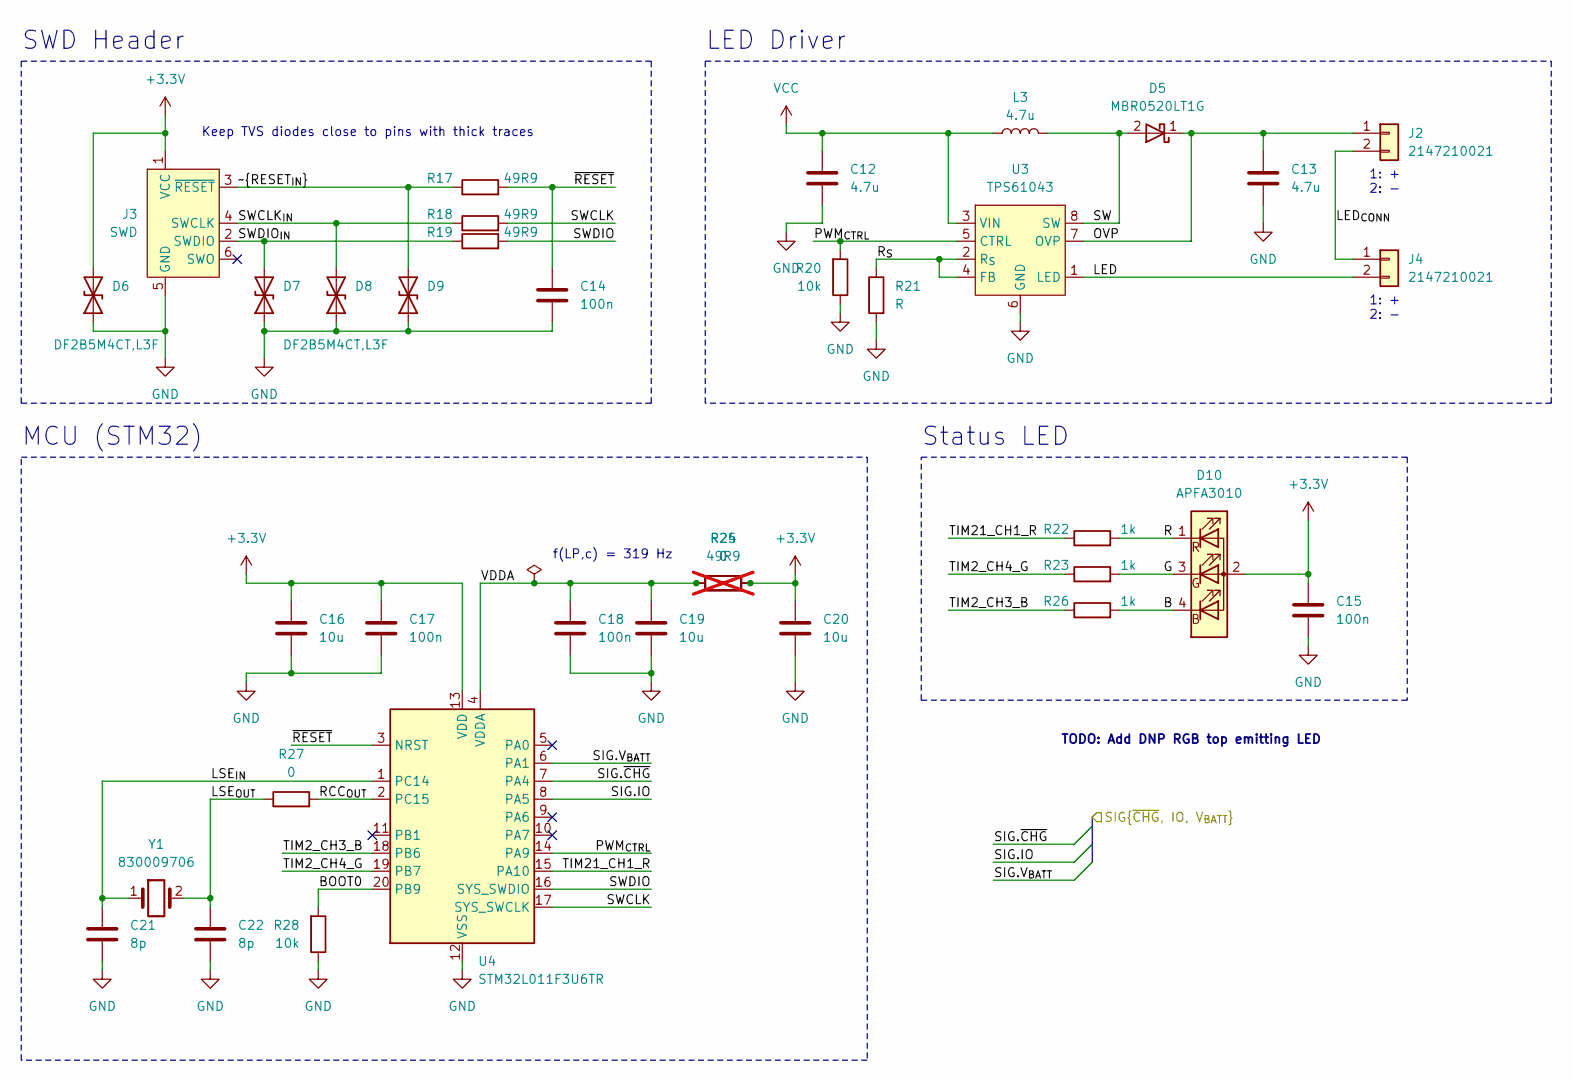
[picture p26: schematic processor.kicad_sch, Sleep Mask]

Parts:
C12, C13: 4.7u; C_0603_1608Metric; Manufacturer_Part_Number GRM188R6YA475KE15D
C14, C15, C17, C18: 100n; C_0402_1005Metric; Manufacturer_Part_Number CL05B104KO5NNNC
C16, C19, C20: 10u; C_0603_1608Metric; Manufacturer_Part_Number CL10X106MO8NRNC
C21, C22: 8p; C_0402_1005Metric; Manufacturer_Part_Number CL05C080DB51PNC
D5: MBR0520LT1G; D_SOD-123; Manufacturer_Part_Number MBR0520LT1G
D6, D7, D8, D9: DF2B5M4CT,L3F; D_SOD-882; Manufacturer_Part_Number DF2B5M4CT,L3F
D10: APFA3010; LED_Kingbright_APFA3010_3x1.5mm_Horizontal; Manufacturer_Part_Number APFA3010LSEEZGKQBKC
J2, J4: 2147210021; Manufacturer_Part_Number 2147210021
J3: SWD; Tag-Connect_TC2030-IDC-NL_2x03_P1.27mm_Vertical
L3: 4.7u; L_0805_2012Metric; Manufacturer_Part_Number MLZ2012N4R7LT000
R17, R18, R19: 49R9; R_0603_1608Metric; Manufacturer_Part_Number RC0603FR-0749R9L
R20, R28: 10k; R_0603_1608Metric; Manufacturer_Part_Number RK73H1JTTD1002F
R21: R; R_0603_1608Metric
R22, R23, R26: 1k; R_0603_1608Metric; Manufacturer_Part_Number RK73H1JTTD1001F
R24: 49R9; R_0603_1608Metric; Manufacturer_Part_Number RC0603FR-0749R9L; not fitted
R25, R27: 0; R_0603_1608Metric; Manufacturer_Part_Number RC0603JR-070RL
U3: TPS61043; Texas_DRB0008A; Manufacturer_Part_Number TPS61043DRBR
U4: STM32L011F3U6TR; ST_UFQFPN-20_3x3mm_P0.5mm; Manufacturer_Part_Number STM32L011F3U6TR
Y1: 830009706; Crystal_SMD_G8-2Pin_3.2x1.5mm; MPN ABS05-32.768KHZ-9-T

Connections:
+3.3V: C15.2, C16.1, C17.1, C20.1, D6.2 (A2), D10.2 (A), J3.1 (VCC), R24.2, R25.2, U4.13 (VDD); also elsewhere on the board
/Power/SIG.IO: U4.8 (PA5); also elsewhere on the board
/Power/SIG.V_{BATT}: U4.6 (PA1); also elsewhere on the board
/Power/SIG.~CHG: U4.7 (PA4); also elsewhere on the board
/Processor/B: D10.4 (B), R26.2
/Processor/BOOT0: R28.2, U4.20 (PB9)
/Processor/G: D10.3 (G), R23.2
/Processor/LED: J4.2, U3.1 (LED)
/Processor/LED_{CONN}: J2.2, J4.1
/Processor/LSE_{IN}: C21.1, U4.1 (PC14), Y1.1
/Processor/LSE_{OUT}: C22.1, R27.1, Y1.2
/Processor/OVP: C13.2, D5.1 (K), J2.1, U3.7 (OVP)
/Processor/PWM_{CTRL}: R20.2, U3.5 (CTRL), U4.14 (PA9)
/Processor/R: D10.1 (R), R22.2
/Processor/RCC_{OUT}: R27.2, U4.2 (PC15)
/Processor/R_{S}: R21.1, U3.2 (R_{S}), U3.4 (FB)
/Processor/SW: D5.2 (A), L3.2, U3.8 (SW)
/Processor/SWCLK: R18.2, U4.17 (SYS_SWCLK)
/Processor/SWCLK_{IN}: D8.2 (A2), J3.4 (SWCLK), R18.1
/Processor/SWDIO: R19.2, U4.16 (SYS_SWDIO)
/Processor/SWDIO_{IN}: D7.2 (A2), J3.2 (SWDIO), R19.1
/Processor/TIM2_CH3_B: R26.1, U4.18 (PB6)
/Processor/TIM2_CH4_G: R23.1, U4.19 (PB7)
/Processor/TIM21_CH1_R: R22.1, U4.15 (PA10)
/Processor/VDDA: C18.1, C19.1, R24.1, R25.1, U4.4 (VDDA)
/Processor/~RESET_{IN}: D9.2 (A2), J3.3 (~RESET), R17.1
/Processor/~RESET: C14.2, R17.2, U4.3 (NRST)
GND: C12.1, C13.1, C14.1, C15.1, C16.2, C17.2, C18.2, C19.2, C20.2, C21.2, C22.2, D6.1 (A1), D7.1 (A1), D8.1 (A1), D9.1 (A1), J3.5 (GND), R20.1, R21.2, R28.1, U3.6 (GND), U3.9 (TP), U4.12 (VSS); also elsewhere on the board
VCC: C12.2, L3.1, U3.3 (VIN); also elsewhere on the board

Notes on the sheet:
Keep TVS diodes close to pins with thick traces
SWD Header
TODO: Add DNP RGB top emitting LED
1: + 2: -
LED Driver
f(LP,c) = 319 Hz
MCU (STM32)
Status LED

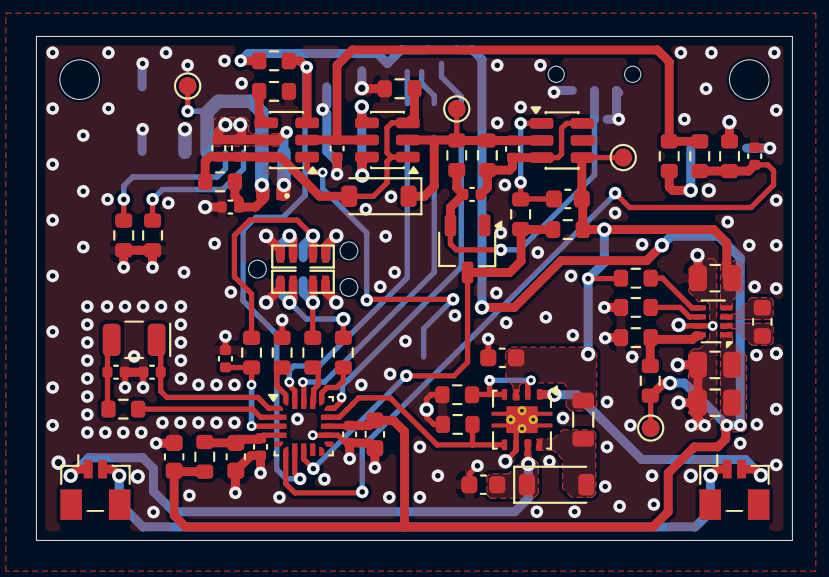
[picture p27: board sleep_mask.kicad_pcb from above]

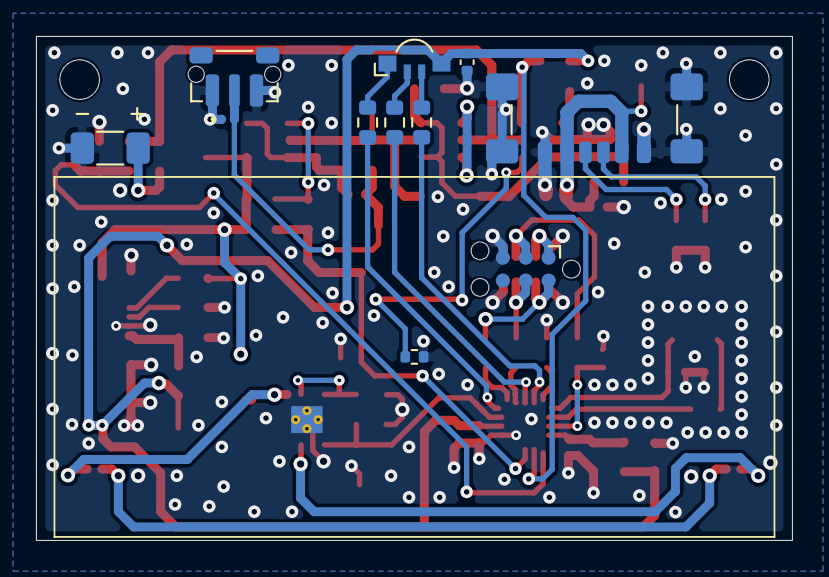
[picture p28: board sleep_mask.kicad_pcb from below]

Board: 4 copper layers, 42.0 x 28.0 mm, 82 parts (11 on the bottom side), 47 nets.

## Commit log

2026-09-04 init commit
    [2147210021.stp, APFA3010.IGS, APFA3010LSEEZGKQBKC.STEP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]
2026-09-04 Revise README with updated overview and PCB images
    Updated the overview to improve clarity and added images of the PCB.
